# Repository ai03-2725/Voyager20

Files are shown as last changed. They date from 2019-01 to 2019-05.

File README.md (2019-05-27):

# Voyager20
A versatile, modern numpad PCB

This is the 20-key variant.
For the 24 key variant with fn row, please see [this](https://github.com/ai03-2725/Voyager20/tree/FnRow).

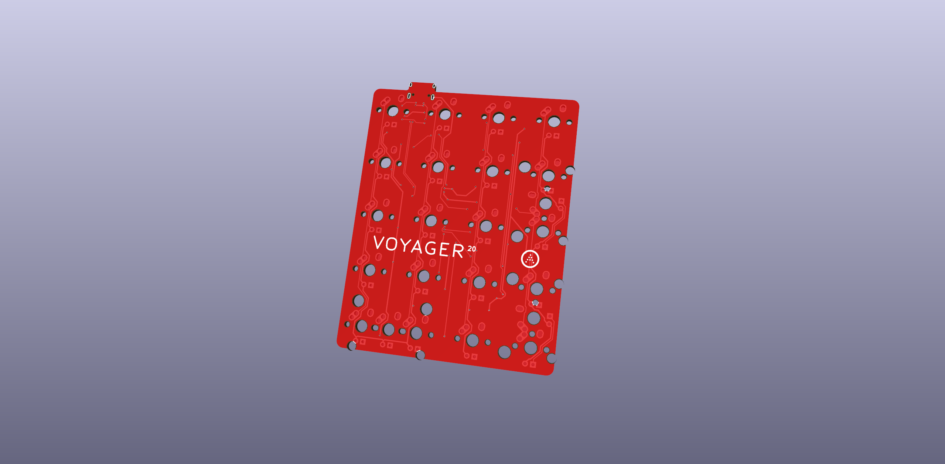
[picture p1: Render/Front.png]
Render


#### In light of recent claims that I am 100% liable for any of my open source PCBs, I am adding this disclaimer.
#### I provide these PCBs as a reference for designing keyboard PCBs. Using them within your projects will require a will to do research of one's own and to learn the workings of them, potentially fixing issues if they exist.
# I provide these PCBs without liability and without any guarantees regarding functionality, as expressed in the MIT license under which all of these PCBs are licensed.

### Features
* In-switch LED backlighting
* RGB underglow
* Decent amount of layout compatibility - 2U positions can be replaced with 2x1U keys
* Over-current and static discharge protection
* Fully open-source

### The Voyager PCB Family
The Voyager PCBs offer fully featured PCBs fit for any keyboard, whether mass production or high-end.

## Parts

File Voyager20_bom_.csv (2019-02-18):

Component | Description | Part | References | Value | Footprint | Quantity Per PCB | Datasheet
1 | Unpolarized capacitor | C_Small | C4 C5 CR1 CR2 CR3 CR4 | 0.1u | C_0603 | 6
2 | Unpolarized capacitor | C_Small | C3 | 1uF | C_0603 | 1
3 | Unpolarized capacitor | C_Small | C1 C2 | 22p | C_0603 | 2
4 | Unpolarized capacitor | C_Small | C6 | 4.7u | C_0603 | 1
5 | Diode, small symbol | D_Small | D1 D2 D3 D4 D5 D6 D7 D8 D10 D11 D12 D13 D14 D15 D16 D17 D19 D20 D21 D22 | SOD-123 | D_SOD-123 | 20 | ~
6 | RGB LED with integrated controller | WS2812B | D9 D18 D23 D24 | WS2812B | LED_WS2812B-PLCC4 | 4 | https://cdn-shop.adafruit.com/datasheets/WS2812B.pdf
7 | resettable fuse, polymeric positive temperature coefficient (PPTC), small symbol | Polyfuse_Small | F1 | 500mA | Fuse_SMD1206_Reflow | 1
8 |  | MX-1U | MX1 MX2 MX3 MX4 MX5 MX6 MX7 MX8 MX9 MX10 MX11 MX12 MX13 MX14 MX15 MX16 MX17 MX18 MX19 MX20 | MX-1U | MX-1U | 20
9 |  | MX-1U | MX-E-1 MX-E-2 MX-E-3 | MX-2U | MX-2U-ReversedStabilizers | 3
10 | Transistor NPN (general) | Q_NPN_BEC | Q1 | Q_NPN_BEC | SOT-23 | 1 | ~
11 | Resistor, small symbol | R_Small | R1 R5 | 10k | R_0805 | 2
12 | Resistor, small symbol | R_Small | R7 R8 R9 R10 R11 R12 R13 R14 R15 R16 R17 R18 R19 R20 R21 R22 R23 R24 R25 R26 R27 | 1k | R_0805 | 21 | ~
13 | Resistor, small symbol | R_Small | R2 R3 | 22 | R_0805 | 2
14 | Resistor, small symbol | R_Small | R4 R6 | 5.1k | R_0805 | 2
15 | Push button switch, generic, two pins | SW_Push | SW1 | SW_Push | SKQG-1155865 | 1
16 | 16MHz, 8kB Flash, 512B SRAM, 512B EEPROM, TQFP-32 | ATmega32U2-AU | U1 | ATmega32U2-AU | QFN-32-1EP_5x5mm_Pitch0.5mm | 1 | http://ww1.microchip.com/downloads/en/DeviceDoc/doc7799.pdf
17 |  | PRTR5V0U2X | U2 | PRTR5V0U2X | SOT143B | 1
18 |  | HRO-TYPE-C-31-M-12 | USB1 | HRO-TYPE-C-31-M-12 | HRO-TYPE-C-31-M-12-Assembly | 1
19 | Four pin crystal, two ground/package pins (pin2 and 4) small symbol | Crystal_GND24_Small | Y1 | 16MHz | Crystal_SMD_3225-4pin_3.2x2.5mm | 1
Component Groups: | 19
Component Count: | 91
Fitted Components: | 91
Number of PCBs: | 1
Total components: | 91
Schematic Version:
Schematic Date:
BoM Date: | 2/17/2019 7:45:39 PM
Schematic Source: | C:\Users\Ryota\Documents\GitHub\Voyager20\Voyager20.sch
KiCad Version: | Eeschema (5.0.0)

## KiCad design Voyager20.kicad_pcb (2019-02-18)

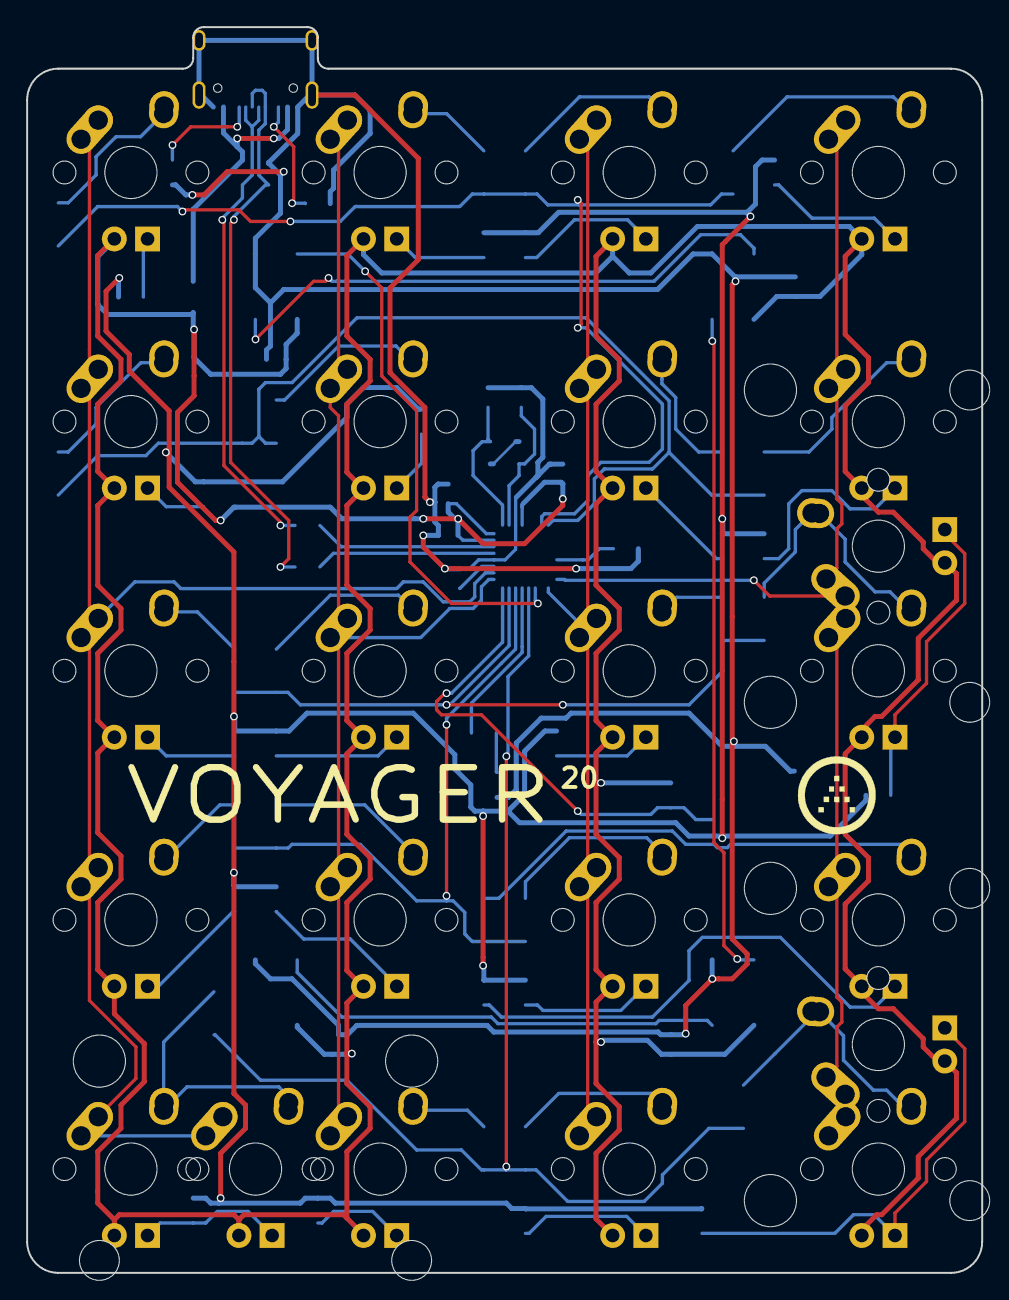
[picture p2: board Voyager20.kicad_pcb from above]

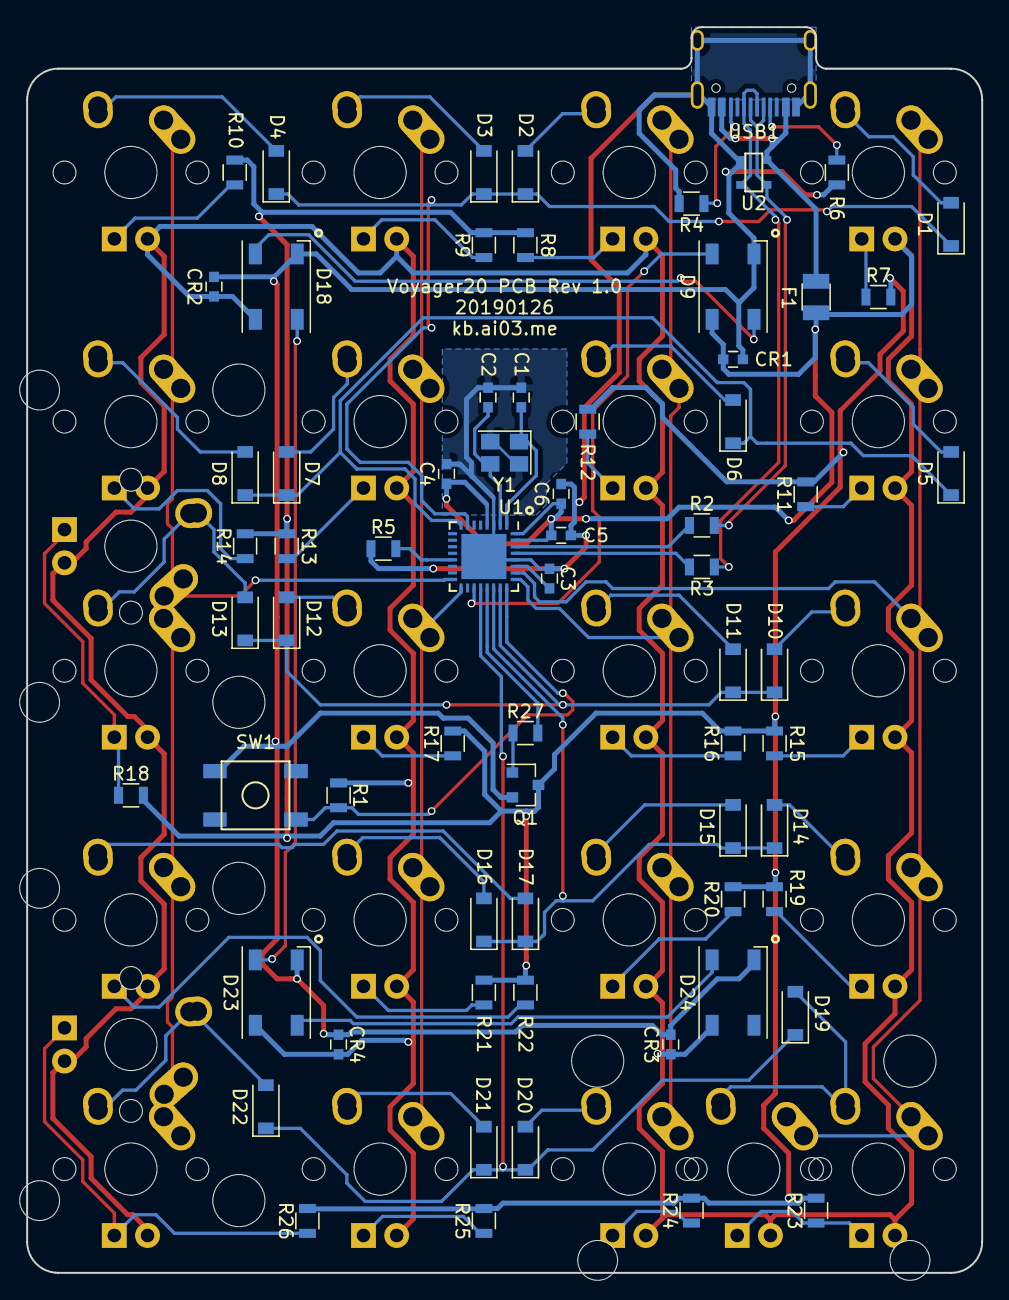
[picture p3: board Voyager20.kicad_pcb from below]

Board: 2 copper layers, 73.0 x 95.2 mm, 91 parts (68 on the bottom side), 70 nets.

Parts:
C1, C2: 22p; C_0603
C3: 1uF; C_0603
C4, C5: 0.1u; C_0603
C6: 4.7u; C_0603
CR1, CR2, CR3, CR4: 0.1u; C_0603
D1, D2, D3, D4, D5, D6, D7, D8, D10, D11, D12, D13, D14, D15, D16, D17, D19, D20, D21, D22: SOD-123; D_SOD-123
D9, D18, D23, D24: WS2812B; LED_WS2812B-PLCC4
F1: 500mA; Fuse_SMD1206_Reflow
MX1, MX2, MX3, MX4, MX5, MX6, MX7, MX8, MX9, MX10, MX11, MX12, MX13, MX14, MX15, MX16, MX17, MX18, MX19, MX20: MX-1U
MX-E-1, MX-E-2, MX-E-3: MX-2U; MX-2U-ReversedStabilizers
Q1: Q_NPN_BEC; SOT-23
R1, R5: 10k; R_0805
R2, R3: 22; R_0805
R4, R6: 5.1k; R_0805
R7, R8, R9, R10, R11, R12, R13, R14, R15, R16, R17, R18, R19, R20, R21, R22, R23, R24, R25, R26, R27: 1k; R_0805
SW1: SW_Push; SKQG-1155865
U1: ATmega32U2-AU; QFN-32-1EP_5x5mm_Pitch0.5mm
U2: PRTR5V0U2X; SOT143B
USB1: HRO-TYPE-C-31-M-12; HRO-TYPE-C-31-M-12-Assembly
Y1: 16MHz; Crystal_SMD_3225-4pin_3.2x2.5mm

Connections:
+5V: C4.1, C5.1, C6.1, CR1.1, CR2.1, CR3.1, CR4.1, D9.1, D18.1, D23.1, D24.1, F1.1, MX1.3, MX2.3, MX3.3, MX4.3, MX5.3, MX6.3, MX7.3, MX8.3, MX9.3, MX10.3, MX11.3, MX12.3, MX13.3, MX14.3, MX15.3, MX16.3, MX17.3, MX18.3, MX19.3, MX20.3, MX-E-1.3, MX-E-2.3, MX-E-3.3, R1.1, U1.4, U1.31, U1.32
COL0: MX1.1, MX5.1, MX9.1, MX13.1, MX17.1, MX-E-3.1, U1.26
COL1: MX2.1, MX6.1, MX10.1, MX14.1, MX18.1, U1.25
COL2: MX3.1, MX7.1, MX11.1, MX15.1, MX19.1, U1.17
COL3: MX4.1, MX8.1, MX12.1, MX16.1, MX20.1, MX-E-1.1, MX-E-2.1, U1.16
D+: R3.2, U1.29
D-: R2.1, U1.30
GND: C1.2, C2.2, C3.2, C4.2, C5.2, C6.2, CR1.2, CR2.2, CR3.2, CR4.2, D9.3, D18.3, D23.3, D24.3, Q1.2, R4.2, R5.1, R6.2, SW1.1, U1.3, U1.28, U2.1, USB1.1, USB1.12, USB1.13, Y1.2, Y1.4
LEDGND: Q1.3, R7.2, R8.2, R9.2, R10.2, R11.2, R12.2, R13.2, R14.2, R15.2, R16.2, R17.2, R18.2, R19.2, R20.2, R21.2, R22.2, R23.2, R24.2, R25.2, R26.2
unnamed: C1.1, U1.1, Y1.1
unnamed: C2.1, U1.2, Y1.3
unnamed: C3.1, U1.27
unnamed: D1.2, MX1.2
unnamed: D2.2, MX2.2
unnamed: D3.2, MX3.2
unnamed: D4.2, MX4.2
unnamed: D5.2, MX5.2
unnamed: D6.2, MX6.2
unnamed: D7.2, MX7.2
unnamed: D8.2, MX8.2
unnamed: D10.2, MX9.2
unnamed: D11.2, MX10.2
unnamed: D12.2, MX11.2
unnamed: D13.2, MX12.2, MX-E-1.2
unnamed: D14.2, MX13.2
unnamed: D15.2, MX14.2
unnamed: D16.2, MX15.2
unnamed: D17.2, MX16.2
unnamed: D18.2, D23.4
unnamed: D9.2, D18.4
unnamed: D19.2, MX17.2, MX-E-3.2
unnamed: D20.2, MX18.2
unnamed: D21.2, MX19.2
unnamed: D22.2, MX20.2, MX-E-2.2
unnamed: D23.2, D24.4
unnamed: MX1.4, R7.1
unnamed: MX2.4, R8.1
unnamed: MX3.4, R9.1
unnamed: MX4.4, R10.1
unnamed: MX5.4, R11.1
unnamed: MX6.4, R12.1
unnamed: MX7.4, R13.1
unnamed: MX8.4, R14.1
unnamed: MX9.4, R15.1
unnamed: MX10.4, R16.1
unnamed: MX11.4, R17.1
unnamed: MX13.4, R19.1
unnamed: MX14.4, R20.1
unnamed: MX15.4, R21.1
unnamed: MX16.4, R22.1
unnamed: MX18.4, R24.1
unnamed: MX19.4, R25.1
unnamed: MX12.4, MX-E-1.4, R18.1
unnamed: MX20.4, MX-E-2.4, R26.1
unnamed: MX17.4, MX-E-3.4, R23.1
unnamed: Q1.1, R27.1
unnamed: R1.2, SW1.2, U1.24
unnamed: R2.2, U2.3, USB1.5, USB1.7
unnamed: R3.1, U2.2, USB1.6, USB1.8
unnamed: R4.1, USB1.10
unnamed: R5.2, U1.13
unnamed: R6.1, USB1.4
unnamed: R27.2, U1.21
RGBLED: D9.4, U1.19
ROW0: D1.1, D2.1, D3.1, D4.1, U1.7
ROW1: D5.1, D6.1, D7.1, D8.1, U1.8
ROW2: D10.1, D11.1, D12.1, D13.1, U1.23
ROW3: D14.1, D15.1, D16.1, D17.1, U1.22
ROW4: D19.1, D20.1, D21.1, D22.1, U1.20
VCC: F1.2, U2.4, USB1.2, USB1.11

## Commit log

2019-01-25 Build schem
    [Matrix.sch, Voyager20.kicad_pcb, Voyager20.sch]
2019-01-27 Build numpad
    [Voyager20-B.Cu.gbl, Voyager20-B.Mask.gbs, Voyager20-B.SilkS.gbo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]
2019-02-18 Voyager20 update
    [Voyager20.kicad_pcb]
2019-02-18 Make BOM
    [Voyager20_bom_.csv]
